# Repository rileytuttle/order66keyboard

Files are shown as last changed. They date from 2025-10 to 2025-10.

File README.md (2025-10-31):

# order66keyboard

BUILDING THIS KEYBOARD

checkout this repo
```
git clone git@github.com:rileytuttle/order66keyboard.git
```

HARDWARE - the assumption here is that you have one of my extra pcbs from the small batch fabrication that I used.
otherwise I guess you could have your own made but I doubt that will happen.
note the version of board you have. I forgot to do this with version 1 so if there is no version then you have a v1.0

next step would be to solder the components on
* solder key hotswap sockets
* solder diodes, currently there are two options (either the smd or DO-35 through hole type). make sure to match cathode with silkscreen marking
* choose what kind of battery you want there is an option for a flat type battery using a jst connector or a 18650 battery with a socket.
* choose the battery toggle switch type
* optionally solder sockets for nice!nano
* solder riser socket for nice!view

CASE
* check out the tag corresponding to the version of pcb you have ie `git checkout v1.0` ... use `git tag` to see tags and `git show tagname` to see the annotations. then `git checkout <VERSION_TAG>`
* then open the case.scad file in openscad. there you will be able to choose features corresponding to the optional hardware you have. export the case stl
* export the keygrid stl
* print the files

[Build Photos](./build-photos/)
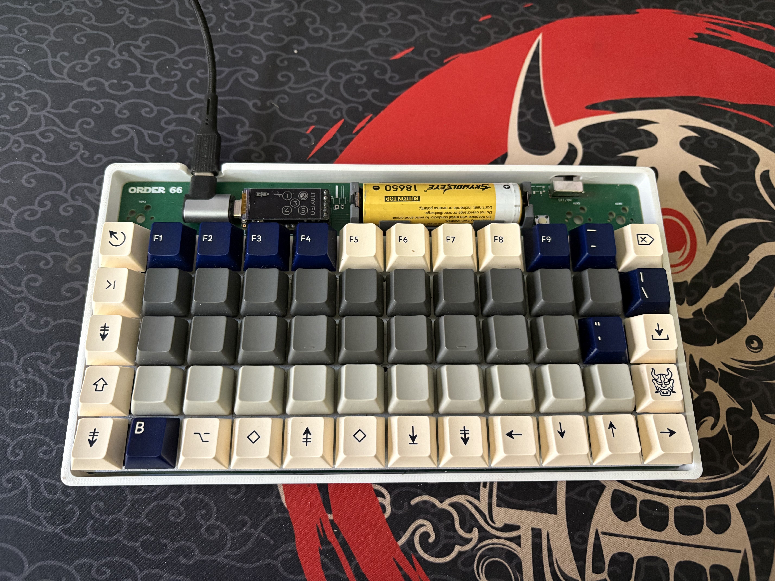
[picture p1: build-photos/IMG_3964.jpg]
complete build


SOFTWARE
* check out the tag corresponding to the pcb version we have
* follow instructions [here](https://zmk.dev/docs/development/local-toolchain/setup/container) to set up zmk devcontainer
* then once in zmk container app folder do this
```
west build -p -b nice_nano_v2 -- -DSHIELD="order66 nice_view_adapter nice_view" -DZMK_EXTRA_MODULES="/workspaces/zmk-modules/order66-shield"
```

NOTE:
once I fix how I created the zmk shield I should be able to move to the "normal" zmk firmware build method. but for now we have to use the local build environment.

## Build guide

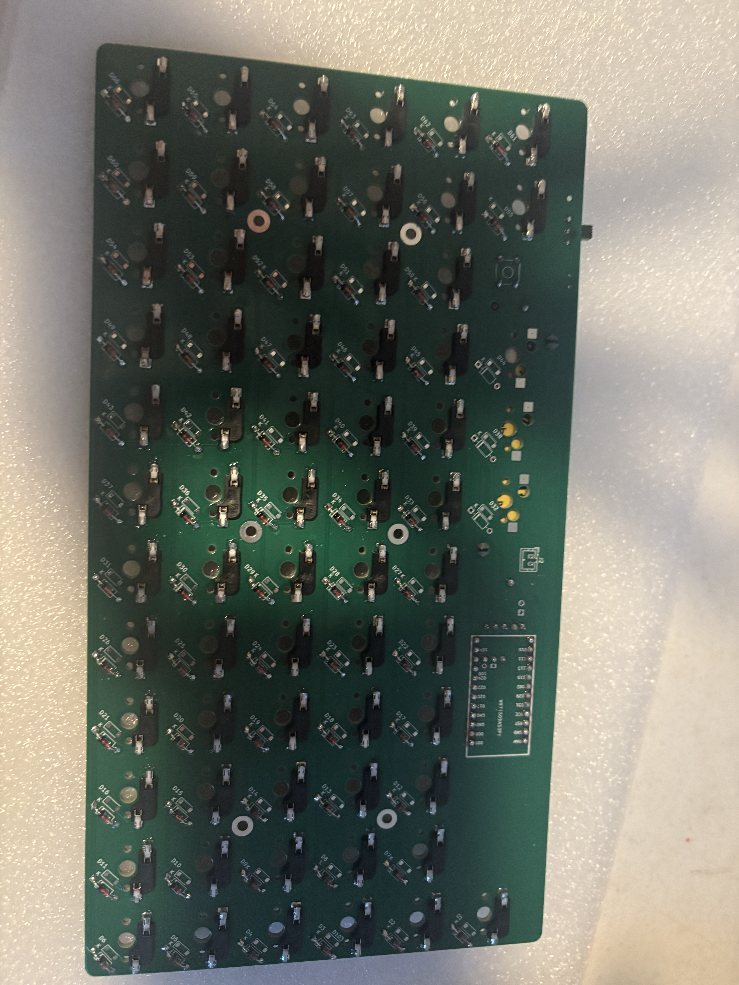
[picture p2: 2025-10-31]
build-photos/IMG_3758.jpg

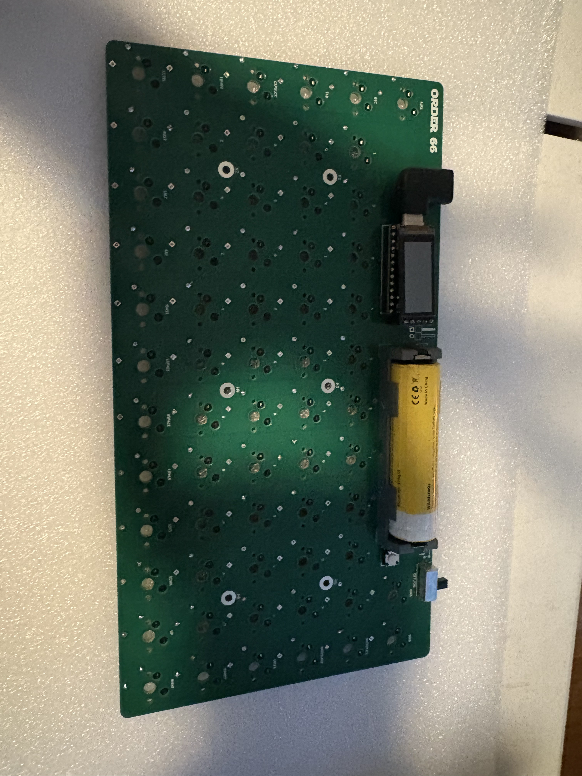
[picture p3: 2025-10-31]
build-photos/IMG_3757.jpg

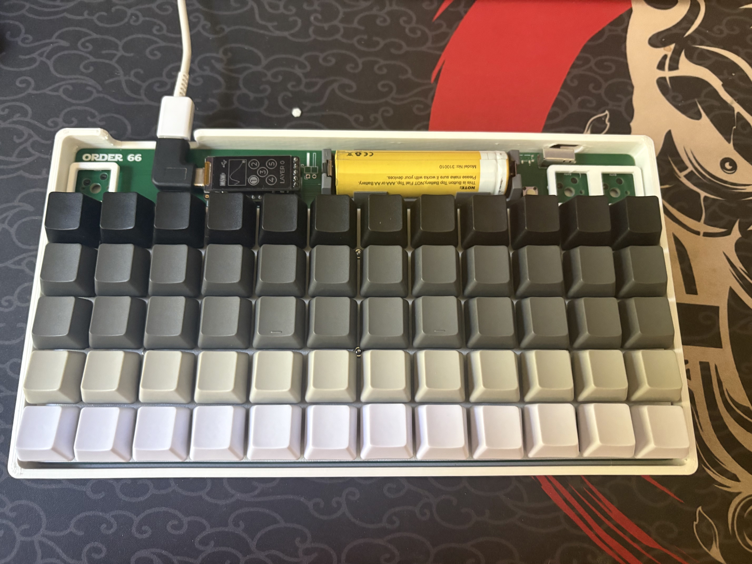
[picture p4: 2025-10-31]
build-photos/IMG_E3760.jpg

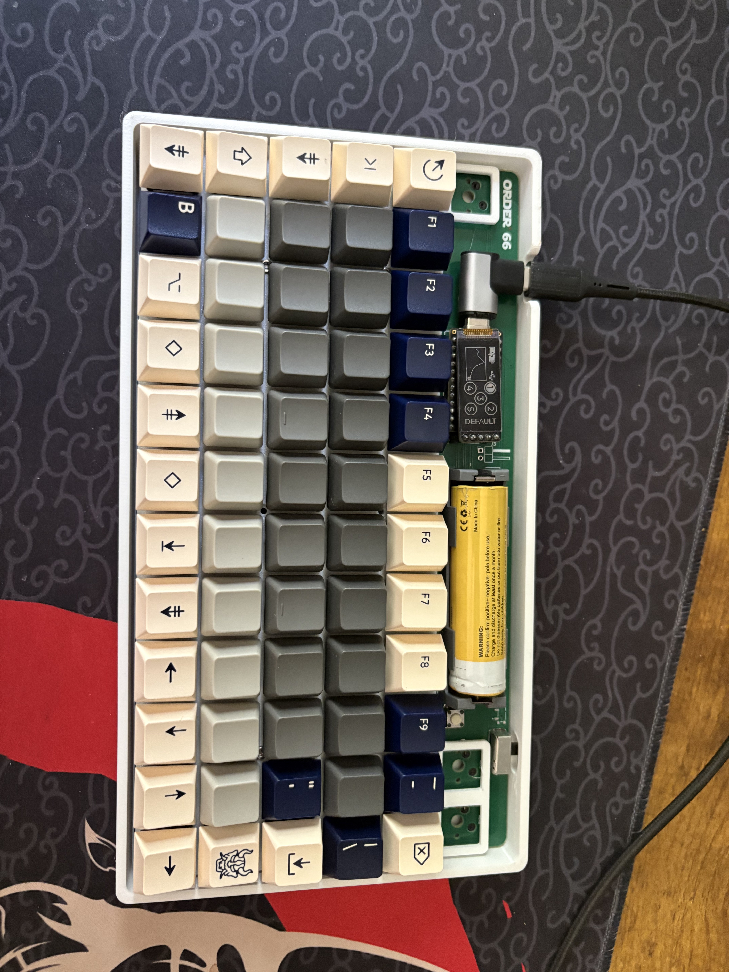
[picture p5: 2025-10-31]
build-photos/IMG_3769.jpg

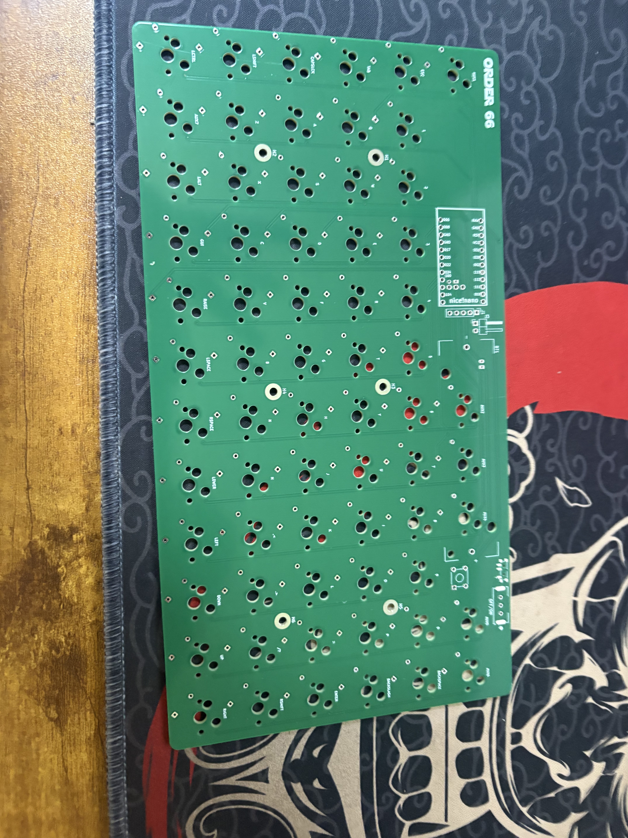
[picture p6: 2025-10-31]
build-photos/IMG_3754.jpg

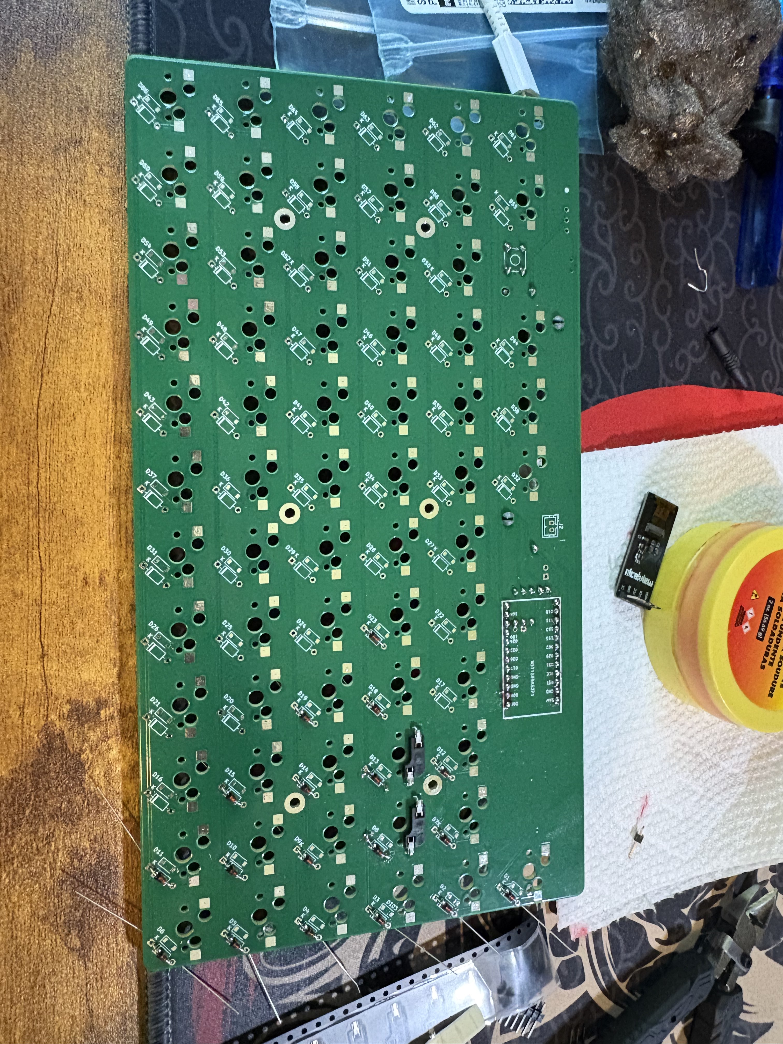
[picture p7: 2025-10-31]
build-photos/IMG_3755.jpg

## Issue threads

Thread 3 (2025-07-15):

wrong spdt layout used

rileytuttle, 2025-07-15:
the one used in the pcb is the right size but doesn't have through holes for the support posts. I had to grind the posts off the switch to use it

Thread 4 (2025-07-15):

on off silkscreen is flipped

rileytuttle, 2025-07-15:
the on off silkscreen for the through hole switch is flipped. should be ON/OFF instead of OFF/ON

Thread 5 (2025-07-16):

case through hole on off switch cutout is not centered correctly

rileytuttle, 2025-07-16:
the part where the toggle switch goes through the case is not centered on the flipper

Closed 2025-07-18.

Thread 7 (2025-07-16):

need to use better hot swap sockets next time

rileytuttle, 2025-07-16:
find better hot swap sockets next time or find whatever keys work best in there. currently the keys I have are all wobbly in there. the key grid helps a bit but should be better

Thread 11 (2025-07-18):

use flat m2 screws for the case

rileytuttle, 2025-07-18:
I want to use m2 screws for attaching the pcb to case. specifically flat head ones.
I think I will leave the pcb as is which I think was set up for 2.5 mm just in case I want to go back to that

Closed 2025-07-18.

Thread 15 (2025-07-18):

EPIC: reconfigure the pcb

rileytuttle, 2025-07-18:
couple things I want
* skinnier footprint. cheaper and can fit in more soft/hard cases for travel
* backlighting
* I would either encoders or an analog pointing device like a trackball or something
* I don't like the usb c right angle connector

do this end I think what I want is adding an extra key width on both sides so something like the footprint of a 5x14
then the nicenano will be placed on the left side such that the port is facing out the back
then the battery can go along the right side. we can still set up something such that the battery type can be swapped if people want

if I go back down to 60 keys I should be able to get a pin back for free
if I re-wire I could reduce down to 16 pins but the wiring may not be worth it

I need at least one pin for the back lighting. not sure how many we need for a mouse like thing but its possible this isn't a possibility.

I could also design this as a two shield thing where one shield is the mouse part but that seems like a lot of work and sort of would just be a separate mouse anyways

rileytuttle, 2025-07-22:
try to use 5050 smd leds ws2812 (these are the single wire control ones. they only have 4 pins to solder)

I think we are in a bit of a bind. If I want backlighting with single color I cannot just use a switch or potentiometer with some voltage divide circuit as these leds would need a pwm signal to decide the brightness. so I would need to free a pin for that

if i wanted to get rgb, zmk only supports underglow not per key rgb

so I think the only real solution here is to ditch the rgb, and ditch the pointing device, free up 1 pin by getting rid of a row
then I can use that pin for backlighting.

that's not a ton of changes. the only difference will be to reduce the footprint to something like a 5x13 or 5x14

rileytuttle, 2025-07-23:
the other experiment I could try would be to make a "split keyboard"
add another nice nano to the mix and then I would need like 5x6 and a 5x6. thats 11 pins on both sides instead of 17. that leaves me with 6 pins to work with on the main board. I could even do most of the keyswitches on the secondary board and the main board would do the lighting and the pointing device

I don't really like this idea though. more "moving" parts, more power draw, I think you can't connect them physically which would be weird. they would be on the same pcb but connected by bluetooth

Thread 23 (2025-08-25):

fix front and back ground plane to be connected to the GND net

rileytuttle, 2025-08-25:
Thinking back I didn't 100% know what I was doing and I think I didn't make sure the ground planes on the front and back copper were connected to the ground net list
For this application it probably isn't the end of the world because ground isn't connected to very much on the board but still

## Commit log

2025-06-20 first commit of order66 keyboard
    [1042.step, order66.kicad_pcb, order66.kicad_sch]
2025-06-23 removing unused library files
    [Gateron-KS33-Socket.step, Kailh-Choc-Socket-CPG135001S30.step, MX-Hotswap-Socket.step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]
2025-06-23 adding pcb images
2025-06-26 Trying though hole diodes (#1)
    * changed to through hole diodes in schematic
    * moved to more through hole components and rerouted traces
    * trying to generate bom
    * reordered the switch and diode numberings to be in order
    * fixing and checking on board design rules to match pcb fabrication
    * starting work on case
    * reorganizing now that case files exists
    * added support for millmax spring loaded swd pins for bootloader support
    [case.scad, order66-bom.csv, order66.kicad_pcb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]
2025-06-26 Trying smd and through hole diodes same time (#2)
    * added the smd sod 123 package diode symbols. havent placed/routed all the footprints yet but seems to be okay. need to figure out what I want to do with the silkscreen references. probably should j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
    * placed all diode footprints. need to sort out the silkscreen overlaps
    * added the other version of power switch that I have as well just in case
    [order66.kicad_pcb, order66.kicad_sch]
2025-06-26 updated pcb front back images and bom
    [order66-bom.csv]
2025-06-30 adding both an order 66 logo and a connector for the jlink but that needs work
    [order66.kicad_pcb, order66.kicad_sch]
2025-06-30 removing the connector for the link for now
    [order66.kicad_pcb, order66.kicad_sch]
2025-07-01 suring up before pcb fab
2025-07-08 rough keyboard case design. needs pcb to test out with
    [case.scad]
2025-07-09 adding some more dimensions to the pcb to aid case design
    [order66.kicad_pcb]
2025-07-18 Working on case after receiving pcb (#10)
    * adds the case and keygrid
    * fixes #5: fixing the switch pass through in case
    [case.scad]
2025-07-18 fixes #11: using flathead screws for the case (#12)
    [case.scad]
2025-07-21 separating all required order 66 keyboard files into different repos to help with versioning (#17)
    [case.scad, order66-bom.csv, order66.kicad_pcb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]
2025-07-21 working on case submodule issue
2025-08-19 keyboard fully works if soldered correctly. display works. needs case work still or longer screws
2025-11-05 updating case
2025-11-05 updating pcb
